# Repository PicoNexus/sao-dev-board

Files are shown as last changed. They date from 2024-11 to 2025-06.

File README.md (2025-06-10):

# SAO Development Board

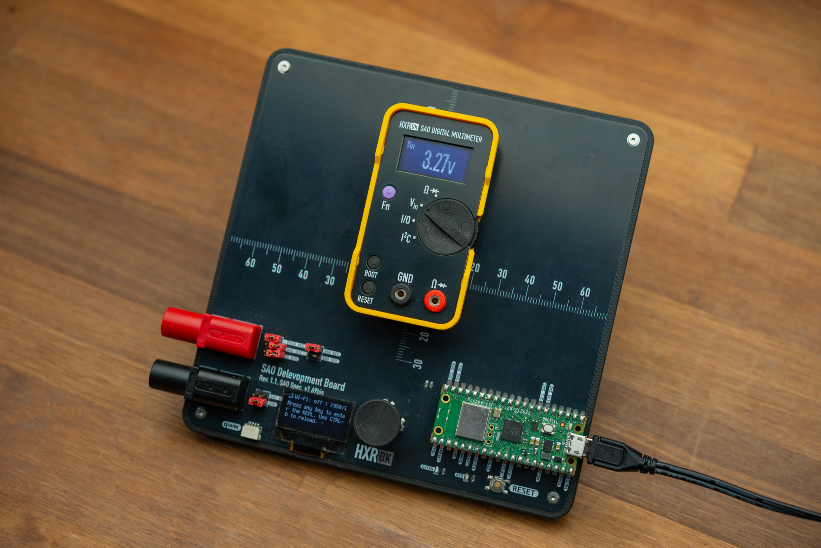
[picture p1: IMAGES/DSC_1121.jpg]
SAO Development Board SAO Development Board with DMM SAO


This is a development and debugging platform for SAOs, standing in for a badge, and based on the Raspberry Pi Pico family of microcontroller boards.

In addition to the Pico, there is a small OLED screen, a few LEDs, reset button and a 5-way navigation switch, to support the badge features.

There is also a set of jumpers and 2 4mm bananaplugs, meant for different ways to power the board and SAO, or for measuring current usage of the SAO using an external tool (eg multimeter or power profiler)

## Designed in KiCad v8.99 (nightly)

To open the project, you will need to install a recent nightly build (og v9 or newer when released), KiCad v8 or earlier won't open this design directly.

## License

The hardware design of the `main` branch of this repository is released under the following license:

* the "Creative Commons Attribution-ShareAlike 4.0 International License"
  (CC BY-SA 4.0) full text of this license is included in the LICENSE file
  and a copy can also be found at
  [http://creativecommons.org/licenses/by-sa/4.0/](http://creativecommons.org/licenses/by-sa/4.0/)

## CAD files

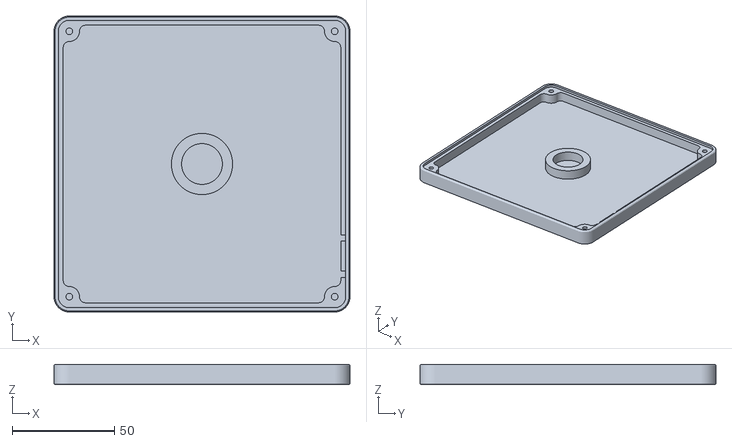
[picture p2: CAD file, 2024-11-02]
case/base.stl
145.0 x 145.0 x 10.0

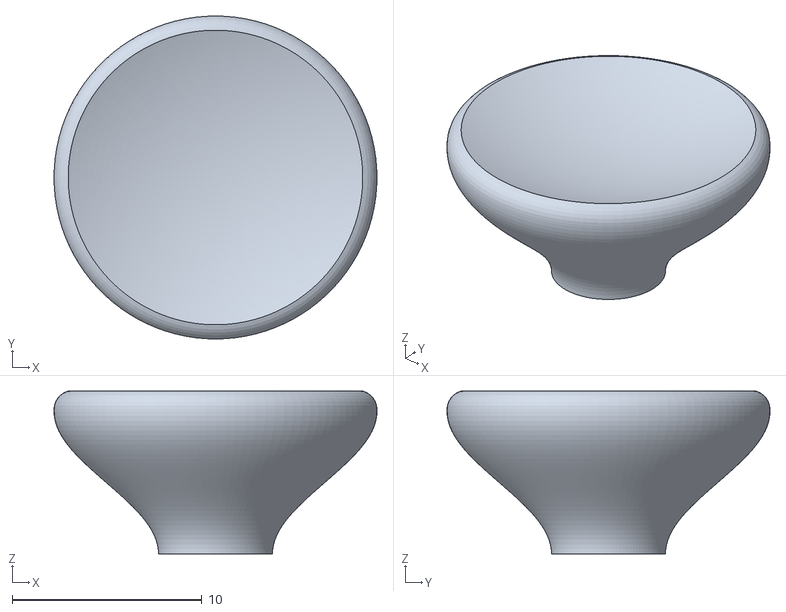
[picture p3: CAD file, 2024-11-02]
case/knob.stl
17.0 x 17.0 x 8.56

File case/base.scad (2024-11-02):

/* 
 * Base for SAO Dev Board
 *
 * Design: hxr.social/@thomasflummer
 *
 * License: CC-BY-SA
 *
 */

module pcb_base(width, length, pcb_thickness, corner_radius, height)
{
    difference()
    {
        union()
        {
            hull()
            {
                for(x = [-1, 1])
                {
                    for(y = [-1, 1])
                    {
                        translate([x*(length/2 - corner_radius), y*(width/2 - corner_radius), height/2])
                            cylinder(r = corner_radius + 2, h = height, center = true, $fn = 150);
                    }
                }

                for(x = [-1, 1])
                {
                    for(y = [-1, 1])
                    {
                        translate([x*(length/2 - corner_radius), y*(width/2 - corner_radius), height/2])
                            cylinder(r = corner_radius + 2 + 0.5, h = height-1, center = true, $fn = 150);
                    }
                }
            }        
        }
        union()
        {
            // PCB cutout
            hull()
            {
                for(x = [-1, 1])
                {
                    for(y = [-1, 1])
                    {
                        translate([x*(length/2 - corner_radius), y*(width/2 - corner_radius), height - pcb_thickness/2])
                            cylinder(r = corner_radius + 0.4, h = pcb_thickness + 0.01, center = true, $fn = 150);
                    }
                }
            }

            // insert cutouts
            for(x = [-1, 1])
            {
                for(y = [-1, 1])
                {
                    translate([x*(length/2 - corner_radius), y*(width/2 - corner_radius), height - (height-2)/2])
                        cylinder(d = 3.3, h =  height-2, center = true, $fn = 50);
                }
            }
            
            // space for PTH
            hull()
            {
                for(x = [-1, 1])
                {
                    for(y = [-1, 1])
                    {
                        translate([x*(length/2 - 3 - 2), y*(width/2 - 3 - corner_radius*2), height - (height-2)/2])
                            cylinder(r = 3, h = height-2, center = true, $fn = 150);
                    }
                }
            }

            hull()
            {
                for(x = [-1, 1])
                {
                    for(y = [-1, 1])
                    {
                        translate([x*(length/2 - 3 - corner_radius*2), y*(width/2 - 3 - 2), height - (height-2)/2])
                            cylinder(r = 3, h = height-2, center = true, $fn = 150);
                    }
                }
            }
    
            difference()
            {
                translate([0, 0, height - (height-2)/2])
                    cube([length - corner_radius*2, width - corner_radius*2, height-2], center = true);

                for(x = [-1, 1])
                {
                    for(y = [-1, 1])
                    {
                        translate([x*(length/2 - corner_radius), y*(width/2 - corner_radius), height - (height-2)/2])
                            cylinder(r = corner_radius, h =  height, center = true, $fn = 150);
                    }
                }
            }
            
            translate([length/2+0.2-3/2, -36.2, height - (height-2)/2])
                cube([3, 3, height-2], center = true);

            translate([length/2+0.2-3/2, -54, height - (height-2)/2])
                cube([3, 3, height-2], center = true);
            
        }
    }
    difference()
    {
        union()
        {
            translate([0, 0, (height - pcb_thickness)/2])
                cylinder(r = 15, h = height - pcb_thickness, center = true, $fn = 200);
        }
        union()
        {
            translate([0, 0, (height - pcb_thickness)/2])
                cylinder(r = 10, h = height, center = true, $fn = 200);
        }
    }
}

pcb_base(140, 140, 1.6, 5, 10);

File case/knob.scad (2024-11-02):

/* 
 * Navigation knob for SAO Dev Board
 *
 * Design: hxr.social/@thomasflummer
 *
 * License: CC-BY-SA
 *
 */

module knob()
{
    difference()
    {
        union()
        {
            start = 6;
            end = 17;
            res = 100;

            for(i = [0:30])
            {
                prev = start - (cos(6*(i+1))*-1 +1)/2 * (start-end);
                current = start - (cos(6*(i))*-1 +1)/2 * (start-end);
                hull()
                {
                    translate([0, 0, 0])
                    translate([0, 0, i*1/4])
                        cylinder(r=current/2, h=0.001,  center = true, $fn = res);

                    translate([0, 0, 0])
                    translate([0, 0, (i+1)*1/4])
                        cylinder(r=(prev)/2, h=0.001,  center = true, $fn = res);
                }
            }
            
            hull()
            {
                translate([0, 0, 7.6])
                rotate_extrude($fn = 100)
                translate([17/2 - 1, 0, 0])
                    circle(r = 1, $fn = 30);
            }            
        }
        union()
        {
            cube([3.2, 3.2, 6], center = true);
            
            translate([0, 0, 7.6 + 20 - 0.6])
                sphere(r = 20, $fn = 300);
        }
    }
}

knob();

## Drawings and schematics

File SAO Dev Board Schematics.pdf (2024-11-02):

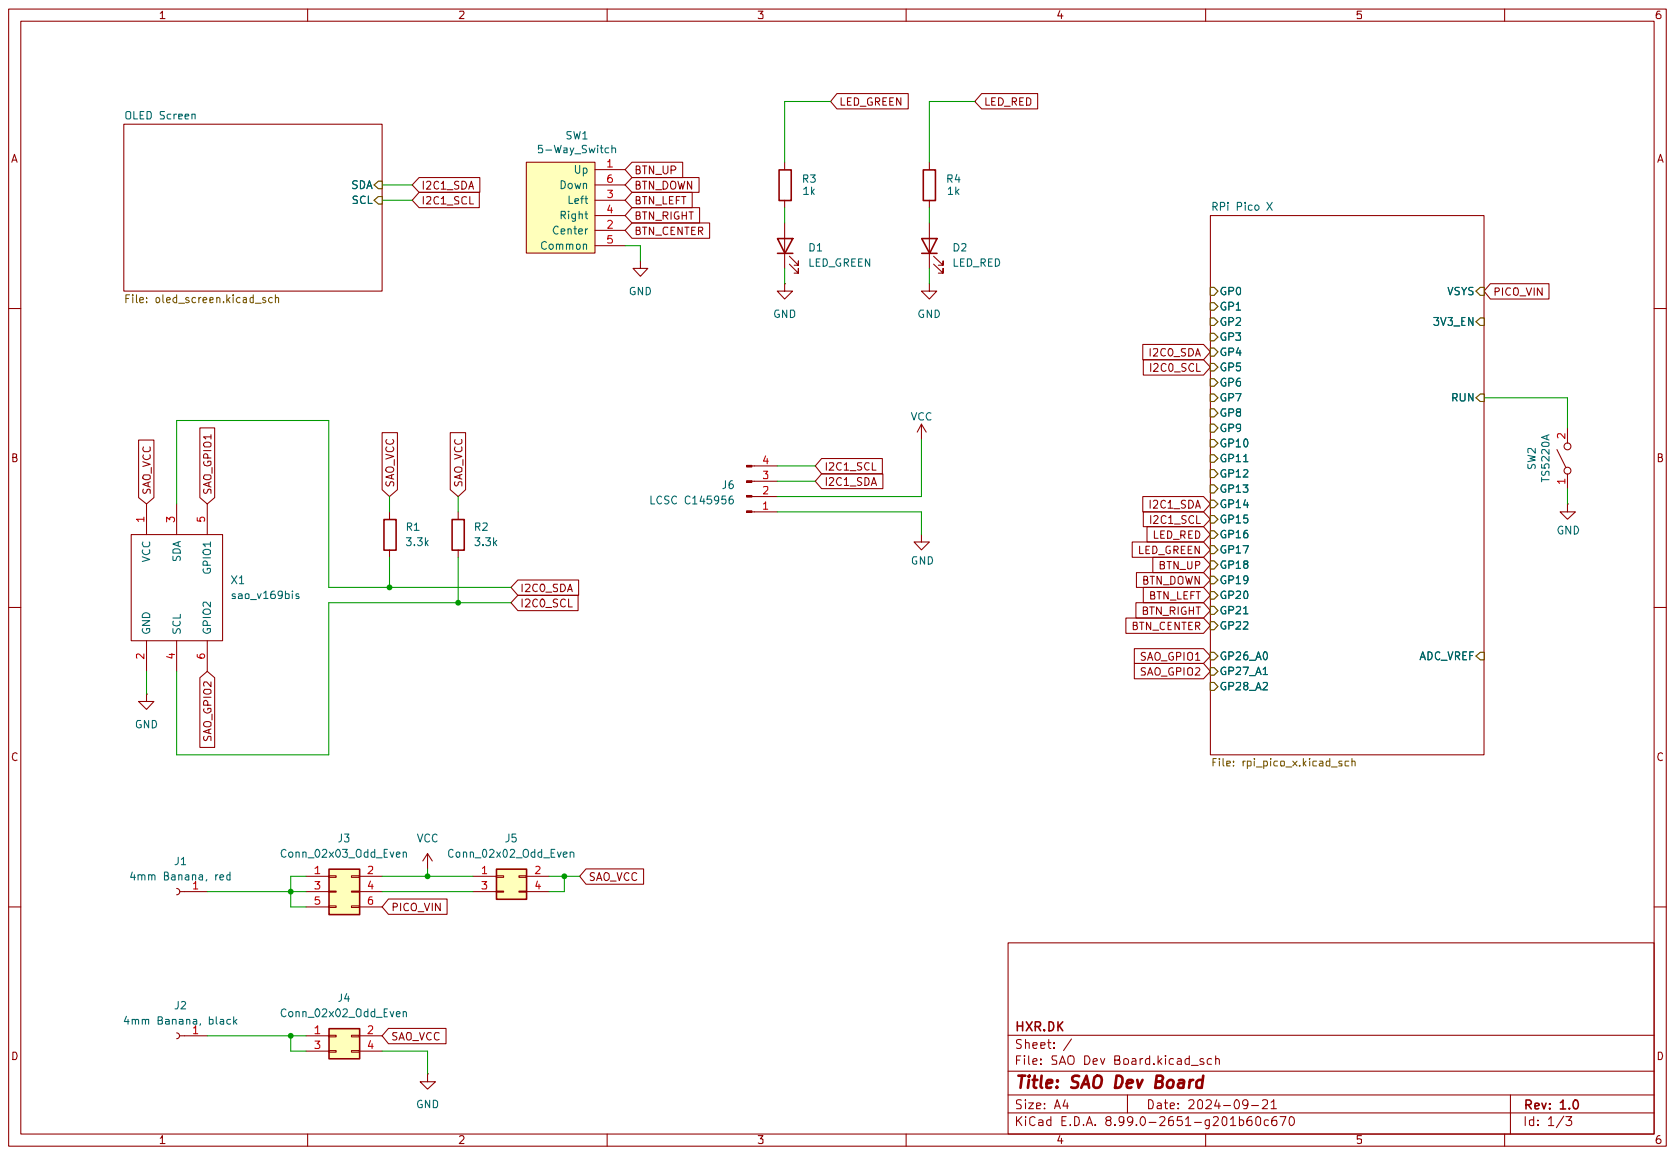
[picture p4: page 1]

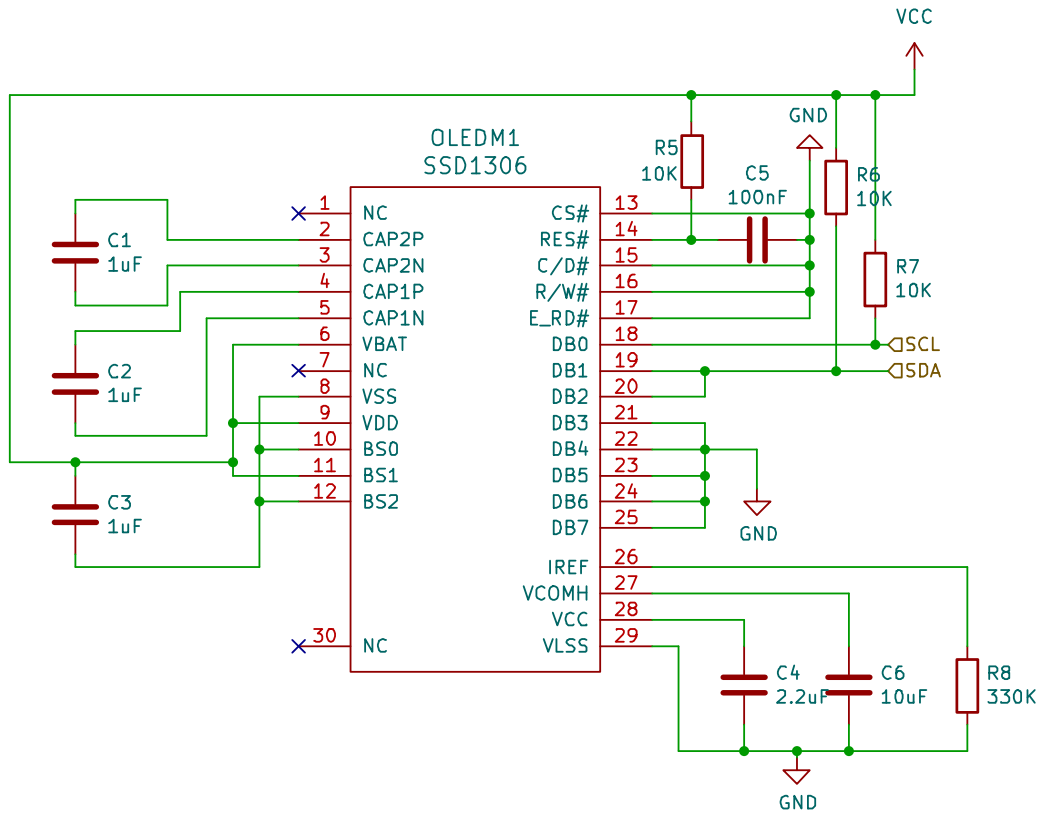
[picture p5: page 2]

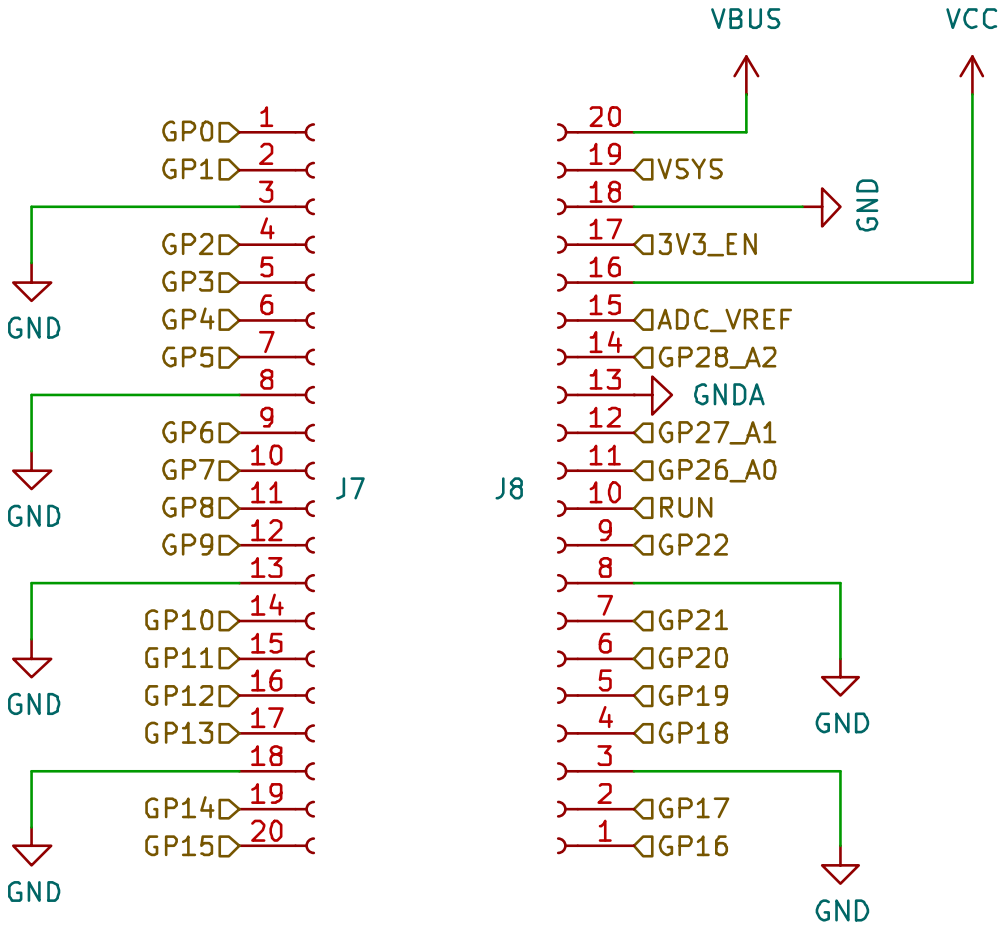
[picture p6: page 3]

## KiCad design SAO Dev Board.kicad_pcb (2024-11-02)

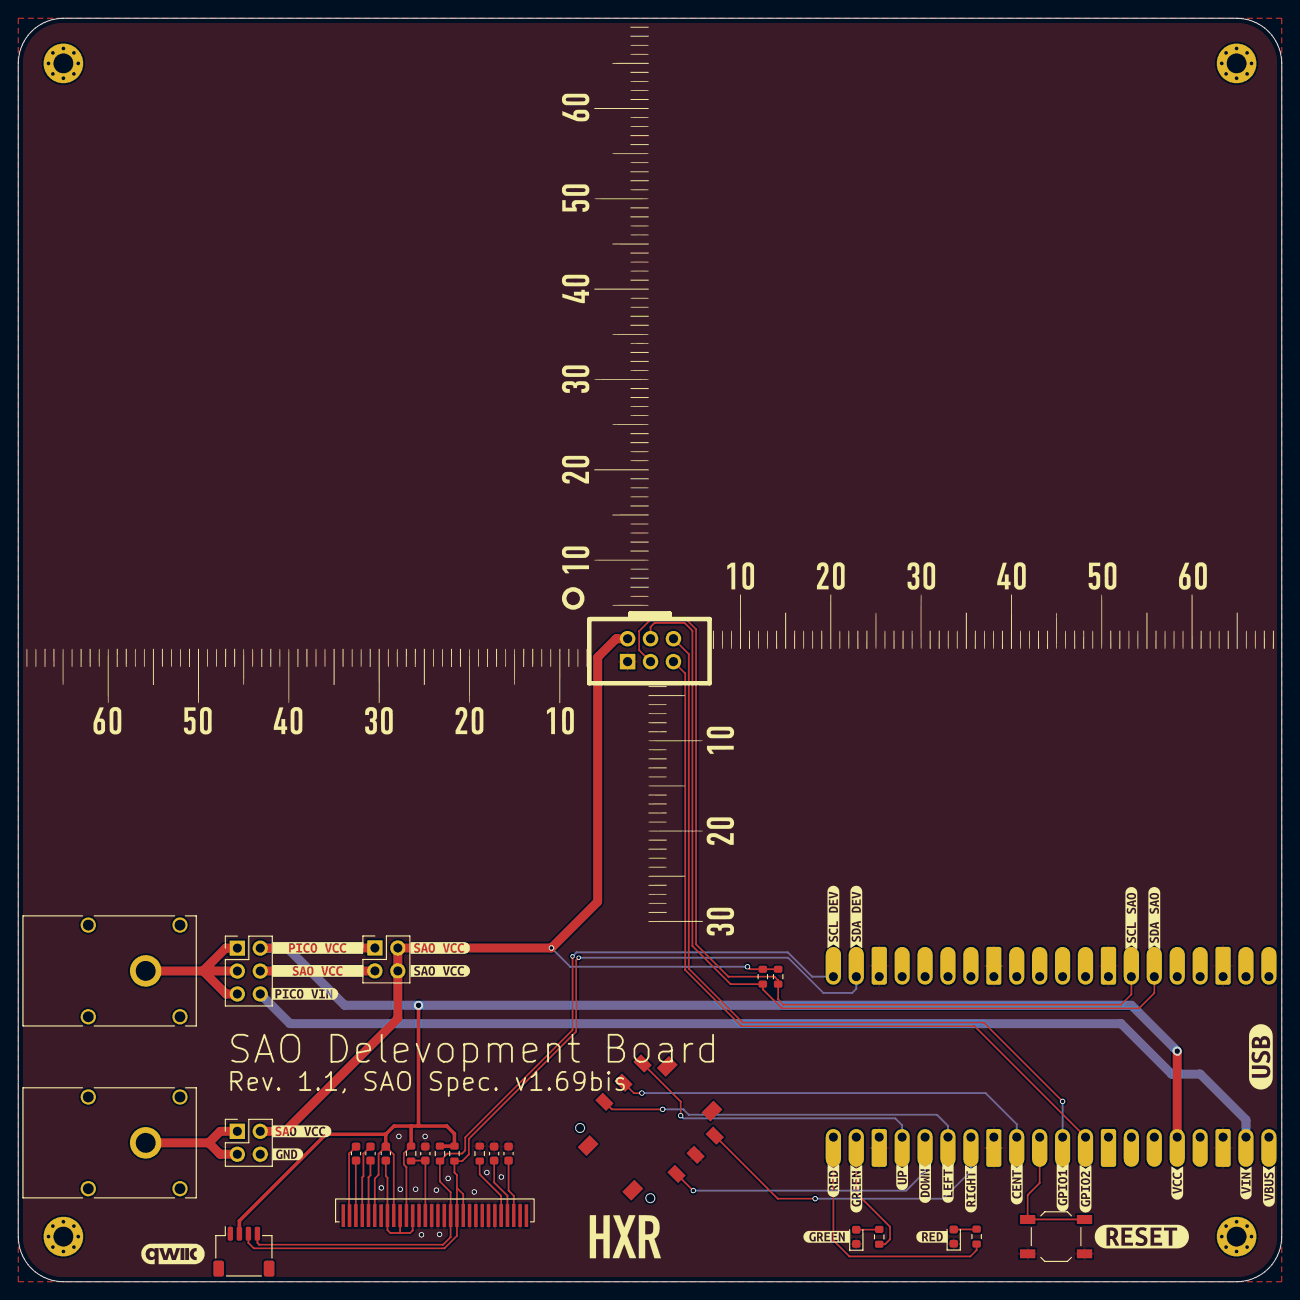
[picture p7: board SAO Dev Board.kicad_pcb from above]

Board: 2 copper layers, 140.0 x 140.0 mm, 55 parts (0 on the bottom side), 32 nets.

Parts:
C1, C2, C3: 1uF; C_0603_1608Metric
C4: 2.2uF; C_0603_1608Metric
C5: 100nF; C_0603_1608Metric
C6: 10uF; C_0603_1608Metric
D1: LED_GREEN; LED_0603_1608Metric
D2: LED_RED; LED_0603_1608Metric
J1: 4mm Banana, red; Banana_Cliff_FCR7350R_S16N-PC_Horizontal
J2: 4mm Banana, black; Banana_Cliff_FCR7350B_S16N-PC_Horizontal
J3: Conn_02x03_Odd_Even; PinHeader_2x03_P2.54mm_Vertical
J4, J5: Conn_02x02_Odd_Even; PinHeader_2x02_P2.54mm_Vertical
J6: LCSC C145956; JST_SH_SM04B-SRSS-TB_1x04-1MP_P1.00mm_Horizontal
J7, J8: Conn_01x20_Socket; PinSocket_1x20_P2.54mm_Vertical
OLEDM1: SSD1306; IROP055-SSD1306Z-PADS-ONLY
R1, R2: 3.3k; R_0603_1608Metric
R3, R4: 1k; R_0603_1608Metric
R5, R6, R7: 10K; R_0603_1608Metric
R8: 330K; R_0603_1608Metric
SW1: 5-Way_Switch; TE-2425755-1
SW2: TS5220A; SW_SPST_TL3342
X1: sao_v169bis; Badgelife-SAOv169-BADGE-2x3
kibuzzard-66F97EBB: G***; kibuzzard-66F97EBB
kibuzzard-66F97F8D: G***; kibuzzard-66F97F8D
kibuzzard-66F97F28: G***; kibuzzard-66F97F28
kibuzzard-66F97F40: G***; kibuzzard-66F97F40
kibuzzard-66F97F94: G***; kibuzzard-66F97F94
kibuzzard-66F97FA0: G***; kibuzzard-66F97FA0
kibuzzard-66F97FBA: G***; kibuzzard-66F97FBA
kibuzzard-66F97FD1: G***; kibuzzard-66F97FD1
kibuzzard-66F97FDE: G***; kibuzzard-66F97FDE
kibuzzard-66F980B1: G***; kibuzzard-66F980B1
kibuzzard-66F981A0: G***; kibuzzard-66F981A0
kibuzzard-66F982A7, kibuzzard-66F982A7#2, kibuzzard-66F982A7#3: G***; kibuzzard-66F982A7
kibuzzard-66F982C8: G***; kibuzzard-66F982C8
kibuzzard-66F982DE: G***; kibuzzard-66F982DE
kibuzzard-66F983EF: G***; kibuzzard-66F983EF
kibuzzard-66F984DA: G***; kibuzzard-66F984DA
kibuzzard-66F9816D: G***; kibuzzard-66F9816D
kibuzzard-66F9817D: G***; kibuzzard-66F9817D
kibuzzard-66F98024: G***; kibuzzard-66F98024
kibuzzard-66F98092: G***; kibuzzard-66F98092
kibuzzard-66F98199: G***; kibuzzard-66F98199
kibuzzard-66F98571: G***; kibuzzard-66F98571
kibuzzard-670E5162: G***; kibuzzard-670E5162
kibuzzard-670E5178: G***; kibuzzard-670E5178
kibuzzard-670E5189: G***; kibuzzard-670E5189

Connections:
/RPi Pico X/RUN: J8.10, SW2.2 (B)
BTN_CENTER: J8.9, SW1.2 (Center)
BTN_DOWN: J8.5, SW1.6 (Down)
BTN_LEFT: J8.6, SW1.3 (Left)
BTN_RIGHT: J8.7, SW1.4 (Right)
BTN_UP: J8.4, SW1.1 (Up)
GND: C4.2, C5.1, C6.2, D1.1 (K), D2.1 (K), J4.4, J6.1, J7.3, J7.8, J7.13, J7.18, J8.3, J8.8, J8.18, OLEDM1.13 (CS#), OLEDM1.15 (C/D#), OLEDM1.16 (R/W#), OLEDM1.17 (E_RD#), OLEDM1.21 (DB3), OLEDM1.22 (DB4), OLEDM1.23 (DB5), OLEDM1.24 (DB6), OLEDM1.25 (DB7), OLEDM1.29 (VLSS), R8.2, SW1.5 (Common), SW2.1 (A), X1.2 (GND)
I2C0_SCL: J7.7, R2.2, X1.4 (SCL)
I2C0_SDA: J7.6, R1.2, X1.3 (SDA)
I2C1_SCL: J6.4, J7.20, OLEDM1.18 (DB0), R7.2
I2C1_SDA: J6.3, J7.19, OLEDM1.19 (DB1), OLEDM1.20 (DB2), R6.2
LED_GREEN: J8.2, R3.1
LED_RED: J8.1, R4.1
unnamed: D1.2 (A), R3.2
unnamed: D2.2 (A), R4.2
unnamed: J1.1, J3.1, J3.3, J3.5
unnamed: J2.1, J4.1, J4.3
unnamed: J3.4, J5.3
unnamed: C3.2, OLEDM1.8 (VSS), OLEDM1.10 (BS0), OLEDM1.12 (BS2)
unnamed: C2.2, OLEDM1.5 (CAP1N)
unnamed: C2.1, OLEDM1.4 (CAP1P)
unnamed: C1.2, OLEDM1.3 (CAP2N)
unnamed: C1.1, OLEDM1.2 (CAP2P)
unnamed: OLEDM1.26 (IREF), R8.1
unnamed: C5.2, OLEDM1.14 (RES#), R5.2
unnamed: C4.1, OLEDM1.28 (VCC)
unnamed: C6.1, OLEDM1.27 (VCOMH)
PICO_VIN: J3.6, J8.19
SAO_GPIO1: J8.11, X1.5 (GPIO1)
SAO_GPIO2: J8.12, X1.6 (GPIO2)
SAO_VCC: J4.2, J5.2, J5.4, R1.1, R2.1, X1.1 (VCC)
VCC: C3.1, J3.2, J5.1, J6.2, J8.16, OLEDM1.6 (VBAT), OLEDM1.9 (VDD), OLEDM1.11 (BS1), R5.1, R6.1, R7.1

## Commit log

2024-11-02 Fixed rotated connector
    [SAO Dev Board-B_Cu.gbl, SAO Dev Board-B_Mask.gbs, SAO Dev Board-B_Paste.gbp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]
2024-11-02 Added 3D printed parts
    [base.scad, base.stl, knob.scad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]
2024-11-02 Added readme, license and schematics as PDF
